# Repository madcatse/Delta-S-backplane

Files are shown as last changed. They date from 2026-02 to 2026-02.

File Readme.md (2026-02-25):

# Delta-S Backplane / Бекплейн для «Дельта‑С»

## RU

### Что это

Этот проект — печатная плата бекплейна для компьютера «Дельта‑С» (совместимая ZX‑архитектура), которая расширяет системную шину и упрощает подключение периферии.

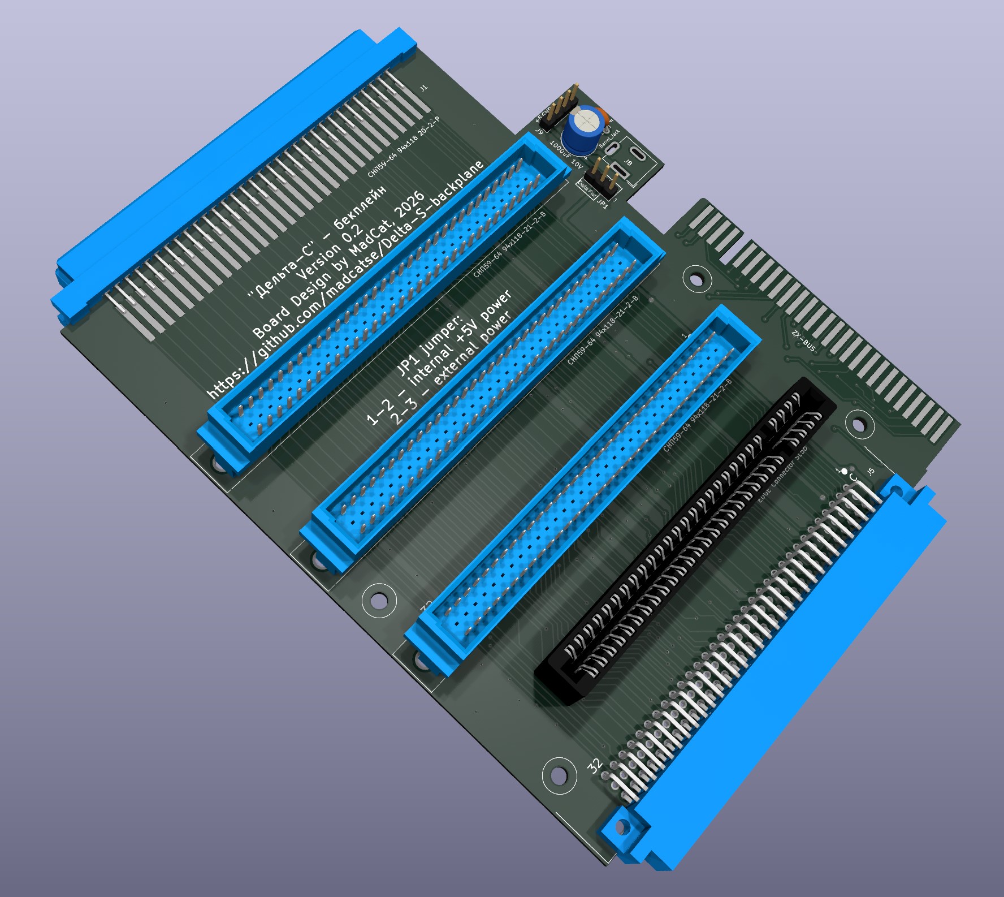
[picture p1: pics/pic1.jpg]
Вид спереди

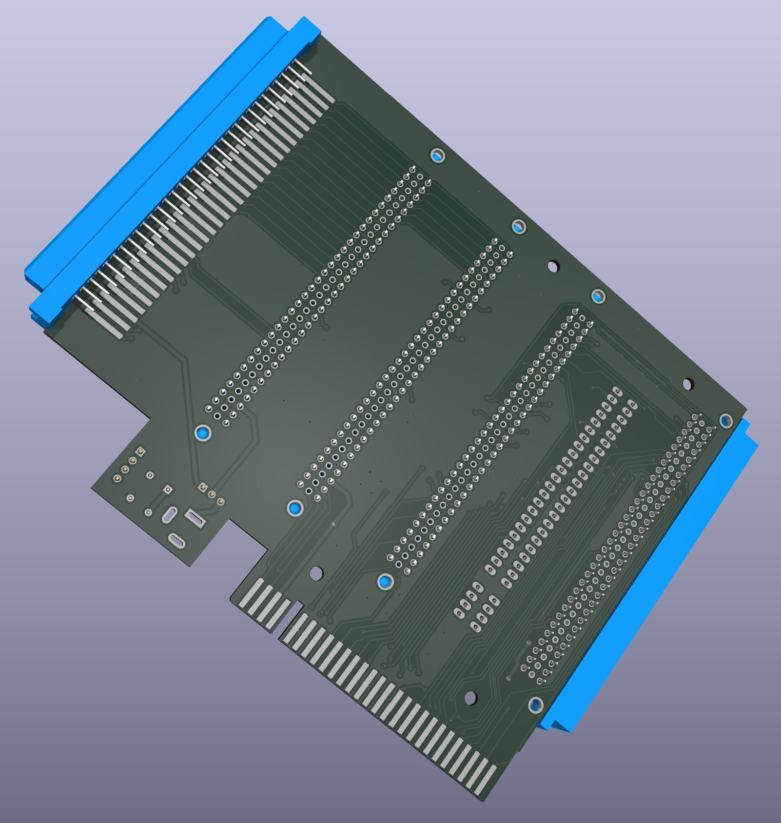
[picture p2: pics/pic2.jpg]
Вид сзади


Плата предназначена для:
- подключения нескольких дополнительных устройств через разъёмы СНП;
- вывода системных сигналов в формате ZX BUS / Nemo Bus;
- питания подключённых устройств либо от компьютера, либо от внешнего источника +5 В с аппаратным выбором источника.

---

### Ключевые возможности

- **4 слота СНП для модулей расширения** (разъёмы J2–J5).
- **Системный вход от компьютера «Дельта‑С»** через угловой СНП‑разъём (J1).
- **Выводы на внешние шины**:
  - J6 — разъём ZX‑BUS;
  - J7 — edge‑разъём формата ZX Spectrum bus.
- **Два варианта питания +5 В**:
  - внутреннее (от хоста «Дельта‑С»);
  - внешнее через barrel‑jack (J8) / штыревой разъём питания (J9).
- **Переключение источника питания джампером JP1**:
  - `1–2` — internal +5V power;
  - `2–3` — external power.
- **Фильтрация питания на плате**: C1 (1000 µF) + C2 (0.1 µF).

---

### Разъёмы и элементы

| Обозначение | Назначение |
|---|---|
| J2, J3, J4, J5 | Слоты СНП для плат расширения |
| J1 | Входной разъём к компьютеру «Дельта‑С» (магистраль бекплейна) |
| J6 | Вывод шины ZX‑BUS |
| J7 | Edge‑разъём шины (ZX Spectrum bus format) |
| J8 | Внешнее питание через DC barrel jack |
| J9 | Штыревой разъём питания/сервисный вывод (+5V/GND) |
| JP1 | Выбор источника +5 В (внутренний/внешний) |
| C1, C2 | Сглаживание и развязка питания |

> Важно: перед установкой `JP1 = 2–3` убедитесь, что внешний источник стабилизирован и соответствует **+5 В DC**.

---

### Что внутри проекта

- `deltas_backplane.kicad_sch` — электрическая схема.
- `deltas_backplane.kicad_pcb` — топология печатной платы.
- `gerbers/` — набор Gerber/Excellon для производства.
- `Libs/` — локальные библиотеки символов, футпринтов и 3D‑моделей.

Проект выполнен в формате KiCad 9‑совместимых файлов.

---

### Производство и сборка

1. Откройте `deltas_backplane.kicad_pcb` в KiCad и визуально проверьте ревизию/маркировки.
2. Используйте готовые файлы из `gerbers/` или сгенерируйте свой комплект под нужную ревизию.
3. После пайки **сначала** установите джампер питания JP1 в нужный режим, **затем** подключайте периферию.
4. При использовании внешнего источника избегайте одновременной «жёсткой» подпитки +5 В от нескольких источников.

---

### Совместимость и контекст

По структуре сигналов проект рассчитан на ZX‑совместимую экосистему «Дельта‑С» с выводом шины в форматах ZX BUS / Nemo Bus. Фактическая совместимость конкретных периферийных устройств зависит от их электрических требований, распиновки и поведения управляющих сигналов.

---

## EN

### What this project is

This repository contains a backplane PCB for the **Delta‑S** computer (ZX‑compatible ecosystem). The board extends the system bus and makes peripheral expansion easier.

It is designed to:
- connect multiple expansion devices through SNP connectors;
- expose system signals in **ZX BUS / Nemo Bus** form factors;
- power attached devices either from the host computer or from an external +5 V source (hardware selectable).

---

### Key features

- **4 SNP expansion slots** (J2–J5).
- **Host connection to Delta‑S** via angled SNP connector (J1).
- **External bus outputs**:
  - J6 — ZX‑BUS connector;
  - J7 — edge connector in ZX Spectrum bus format.
- **Dual +5 V power options**:
  - internal (from the Delta‑S host);
  - external via barrel jack (J8) / header connector (J9).
- **JP1 power source selection**:
  - `1–2` — internal +5V power;
  - `2–3` — external power.
- **Onboard power filtering**: C1 (1000 µF) + C2 (0.1 µF).

---

### Connectors and parts

| Designator | Function |
|---|---|
| J2, J3, J4, J5 | SNP slots for expansion cards |
| J1 | Upstream connector to Delta‑S host bus |
| J6 | ZX‑BUS output |
| J7 | Edge bus connector (ZX Spectrum format) |
| J8 | External power input (DC barrel jack) |
| J9 | Pin header for power/service (+5V/GND) |
| JP1 | +5 V source select (internal/external) |
| C1, C2 | Bulk/decoupling capacitors |

> Important: before setting `JP1 = 2–3`, verify that your external PSU is properly regulated at **+5 V DC**.

---

### Repository contents

- `deltas_backplane.kicad_sch` — schematic.
- `deltas_backplane.kicad_pcb` — board layout.
- `gerbers/` — manufacturing Gerber/Excellon files.
- `Libs/` — local symbols, footprints, and 3D models.

The project uses KiCad file formats compatible with KiCad 9 workflows.

---

### Manufacturing and bring‑up notes

1. Open `deltas_backplane.kicad_pcb` in KiCad and confirm board revision/silkscreen.
2. Use the prepared set in `gerbers/` (or regenerate for your target revision).
3. After assembly, set JP1 to the required power mode **before** attaching expansion cards.
4. When using external power, avoid hard‑tying multiple +5 V sources without proper isolation.

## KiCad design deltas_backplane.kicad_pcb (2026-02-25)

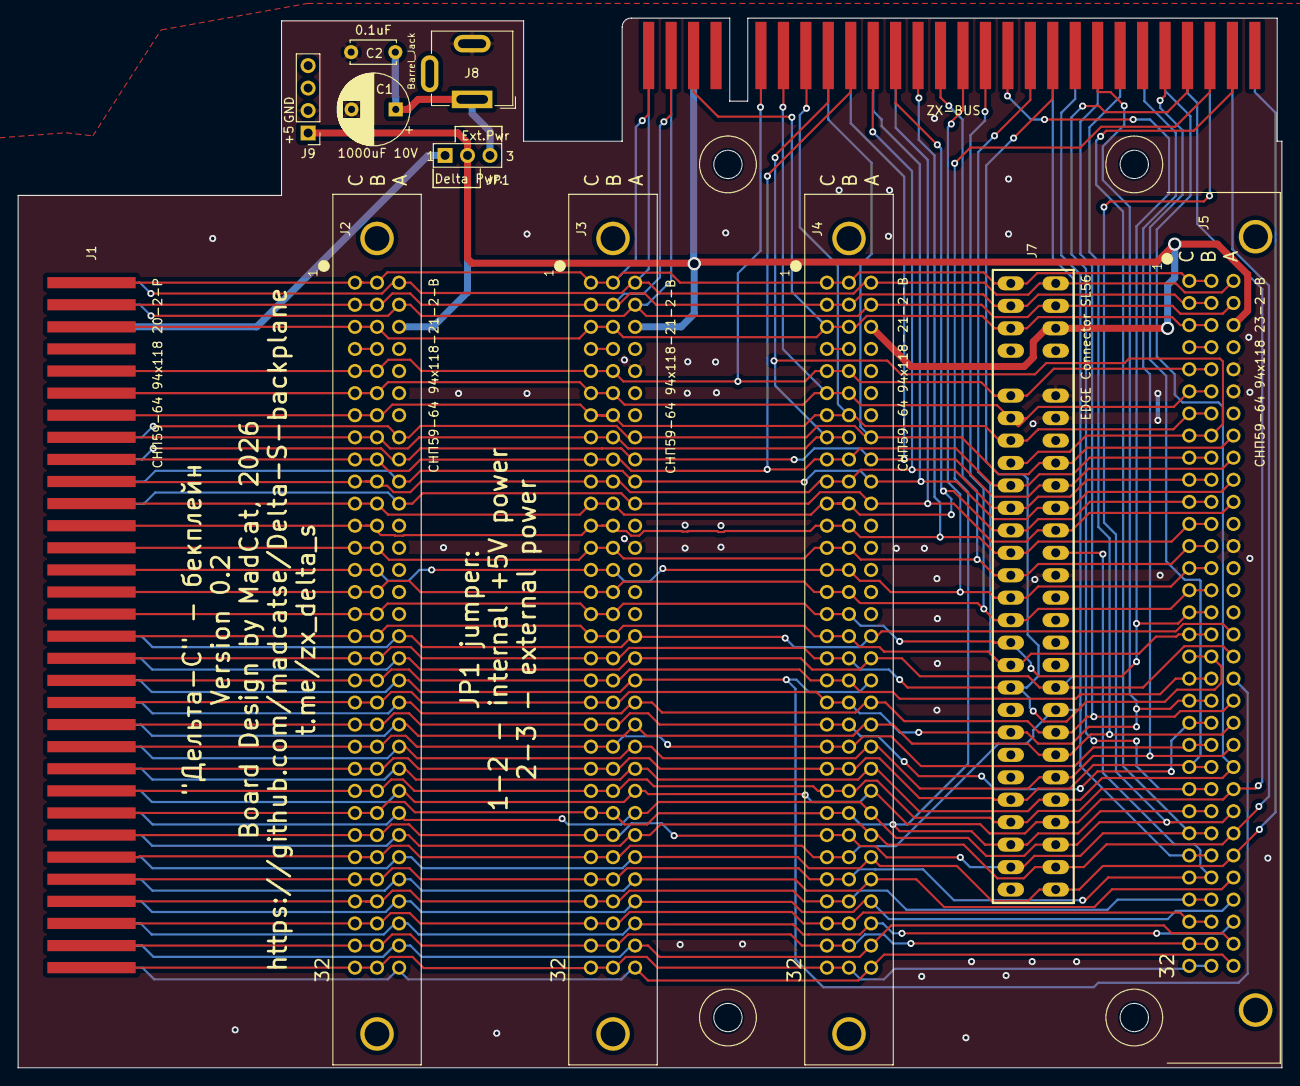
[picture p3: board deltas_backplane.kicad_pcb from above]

Board: 2 copper layers, 143.0 x 118.8 mm, 16 parts (0 on the bottom side), 57 nets.

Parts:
C1: 1000uF 10V; CP_Radial_D8.0mm_P5.00mm
C2: 0.1uF; C_Disc_D5.0mm_W2.5mm_P5.00mm
J1: СНП59-64 94х118 20-2-Р; snp_straight
J2, J3, J4: СНП59-64 94х118-21-2-В; snp59_96_male_straight
J5: СНП59-64 94х118 23-2-В; snp59_96_female_angle_3
J6: ZX-BUS; ZX SPECTRUM EDGE CONNECTOR (HORIZONTAL)
J7: EDGE Connector SL56; Spectrum_edge_slot_FIXED
J8: Barrel_Jack; BarrelJack_GCT_DCJ200-10-A_Horizontal
J9: Conn_01x04; PinHeader_1x04_P2.54mm_Vertical
JP1: Jumper_3_Open; PinHeader_1x03_P2.54mm_Vertical
M31, M31#2, M31#3, M31#4: MountingHole_3.2mm_M3

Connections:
5V_connector: J2.35 ("+5"), J3.35 ("+5"), J4.35 ("+5"), J5.35 ("+5"), J6.31 (+5V), J7.31 (+5V), J9.1, JP1.2 (C)
+5V: J1.35 ("+5"), JP1.1 (A)
A0: J1.40 (A0), J2.40 (A0), J3.40 (A0), J4.40 (A0), J5.40 (A0), J6.37 (A0), J7.37 (A0)
A1: J1.41 (A1), J2.41 (A1), J3.41 (A1), J4.41 (A1), J5.41 (A1), J6.38 (A1), J7.38 (A1)
A2: J1.42 (A2), J2.42 (A2), J3.42 (A2), J4.42 (A2), J5.42 (A2), J6.39 (A2), J7.39 (A2)
A3: J1.43 (A3), J2.43 (A3), J3.43 (A3), J4.43 (A3), J5.43 (A3), J6.40 (A3), J7.40 (A3)
A4: J1.55 (A4), J2.55 (A4), J3.55 (A4), J4.55 (A4), J5.55 (A4), J6.52 (A4), J7.52 (A4)
A5: J1.54 (A5), J2.54 (A5), J3.54 (A5), J4.54 (A5), J5.54 (A5), J6.51 (A5), J7.51 (A5)
A6: J1.53 (A6), J2.53 (A6), J3.53 (A6), J4.53 (A6), J5.53 (A6), J6.50 (A6), J7.50 (A6)
A7: J1.52 (A7), J2.52 (A7), J3.52 (A7), J4.52 (A7), J5.52 (A7), J6.49 (A7), J7.49 (A7)
A8: J1.25 (A8), J2.25 (A8), J3.25 (A8), J4.25 (A8), J5.25 (A8), J6.26 (A8), J7.26 (A8)
A9: J1.58 (A9), J2.58 (A9), J3.58 (A9), J4.58 (A9), J5.58 (A9), J6.55 (A9), J7.55 (A9)
A10: J1.26 (A10), J2.26 (A10), J3.26 (A10), J4.26 (A10), J5.26 (A10), J6.27 (A10), J7.27 (A10)
A11: J1.59 (A11), J2.59 (A11), J3.59 (A11), J4.59 (A11), J5.59 (A11), J6.56 (A11), J7.56 (A11)
A12: J1.34 (A12), J2.34 (A12), J3.34 (A12), J4.34 (A12), J5.34 (A12), J6.30 (A12), J7.30 (A12)
A13: J1.2 (A13), J2.2 (A13), J3.2 (A13), J4.2 (A13), J5.2 (A13), J6.2 (A13), J7.2 (A13)
A14: J1.33 (A14), J2.33 (A14), J3.33 (A14), J4.33 (A14), J5.33 (A14), J6.29 (A14), J7.29 (A14)
A15: J1.1 (A15), J2.1 (A15), J3.1 (A15), J4.1 (A15), J5.1 (A15), J6.1 (A15), J7.1 (A15)
A19_SNP: J1.51 (BD1), J2.51 (BD1), J3.51 (BD1), J4.51 (BD1), J5.51 (BD1)
A28_SNP: J1.60 (P5), J2.60 (P5), J3.60 (P5), J4.60 (P5), J5.60 (P5)
A29_SNP: J1.61 (BD3), J2.61 (BD3), J3.61 (BD3), J4.61 (BD3), J5.61 (BD3)
A30_SNP: J1.62 (BD5), J2.62 (BD5), J3.62 (BD5), J4.62 (BD5), J5.62 (BD5)
A31_SNP: J1.63 (BD6), J2.63 (BD6), J3.63 (BD6), J4.63 (BD6), J5.63 (BD6)
B19_SNP: J1.19 (BD2), J2.19 (BD2), J3.19 (BD2), J4.19 (BD2), J5.19 (BD2)
B21_SNP: J1.21 (P1), J2.21 (P1), J3.21 (P1), J4.21 (P1), J5.21 (P1)
B22_SNP: J1.22 (P2), J2.22 (P2), J3.22 (P2), J4.22 (P2), J5.22 (P2)
B28_SNP: J1.28 (P4), J2.28 (P4), J3.28 (P4), J4.28 (P4), J5.28 (P4), J7.41 (NC)
B29_SNP: J1.29 (P5), J2.29 (P5), J3.29 (P5), J4.29 (P5), J5.29 (P5)
B30_SNP: J1.30 (BD4), J2.30 (BD4), J3.30 (BD4), J4.30 (BD4), J5.30 (BD4)
B31_SNP: J1.31 (BD0), J2.31 (BD0), J3.31 (BD0), J4.31 (BD0), J5.31 (BD0)
B32_SNP: J1.32 (BD7), J2.32 (BD7), J3.32 (BD7), J4.32 (BD7), J5.32 (BD7)
BUSY: J1.64 (ГТ), J2.64 (ГТ), J3.64 (ГТ), J4.64 (ГТ), J5.64 (ГТ)
D0: J1.5 (D0), J2.5 (D0), J3.5 (D0), J4.5 (D0), J5.5 (D0), J6.6 (D0), J7.6 (D0)
D1: J1.6 (D1), J2.6 (D1), J3.6 (D1), J4.6 (D1), J5.6 (D1), J6.7 (D1), J7.7 (D1)
D2: J1.7 (D2), J2.7 (D2), J3.7 (D2), J4.7 (D2), J5.7 (D2), J6.8 (D2), J7.8 (D2)
D3: J1.10 (D3), J2.10 (D3), J3.10 (D3), J4.10 (D3), J5.10 (D3), J6.11 (D3), J7.11 (D3)
D4: J1.11 (D4), J2.11 (D4), J3.11 (D4), J4.11 (D4), J5.11 (D4), J6.12 (D4), J7.12 (D4)
D5: J1.9 (D5), J2.9 (D5), J3.9 (D5), J4.9 (D5), J5.9 (D5), J6.10 (D5), J7.10 (D5)
D6: J1.8 (D6), J2.8 (D6), J3.8 (D6), J4.8 (D6), J5.8 (D6), J6.9 (D6), J7.9 (D6)
D7: J1.3 (D7), J2.3 (D7), J3.3 (D7), J4.3 (D7), J5.3 (D7), J6.3 (D7), J7.3 (D7)
GND: C1.2, C2.2, J1.37 (Общий), J1.38 (Общий), J1.45 (Общий), J2.37 (Общий), J2.38 (Общий), J2.45 (Общий), J3.37 (Общий), J3.38 (Общий), J3.45 (Общий), J4.37 (Общий), J4.38 (Общий), J4.45 (Общий), J5.37 (Общий), J5.38 (Общий), J5.45 (Общий), J6.34 (GND), J6.35 (GND), J6.42 (GND), J7.34 (GND), J7.35 (GND), J7.42 (GND), J8.2, J9.2
M1L: J1.23 (М1), J2.23 (М1), J3.23 (М1), J4.23 (М1), J5.23 (М1), J6.24 (M1), J7.24 (M1)
unnamed: C1.1, C2.1, J8.1, JP1.3 (B)
STROBL: J1.49 (СТР), J2.49 (СТР), J3.49 (СТР), J4.49 (СТР), J5.49 (СТР)
ВУL: J1.16 (ВУ), J2.16 (ВУ), J3.16 (ВУ), J4.16 (ВУ), J5.16 (ВУ), J6.17 (IORQ), J7.17 (IORQ)
ЗАПРШL: J1.50 (ЗАПРШ), J2.50 (ЗАПРШ), J3.50 (ЗАПРШ), J4.50 (ЗАПРШ), J5.50 (ЗАПРШ), J6.47 (BUSRQ), J7.47 (BUSRQ)
ЗПL: J1.18 (ЗП), J2.18 (ЗП), J3.18 (ЗП), J4.18 (ЗП), J5.18 (ЗП), J6.19 (WR), J7.19 (WR)
НПРL: J1.13 (НПР), J2.13 (НПР), J3.13 (НПР), J4.13 (НПР), J5.13 (НПР), J6.14 (NMI), J7.14 (NMI)
ОЖИДL: J1.20 (ОЖИД), J2.20 (ОЖИД), J3.20 (ОЖИД), J4.20 (ОЖИД), J5.20 (ОЖИД), J6.21 (WAIT), J7.21 (WAIT)
ОЗУL: J1.15 (ОЗУ), J2.15 (ОЗУ), J3.15 (ОЗУ), J4.15 (ОЗУ), J5.15 (ОЗУ), J6.16 (MREQ), J7.16 (MREQ)
ПЗШL: J1.57 (ПЗШ), J2.57 (ПЗШ), J3.57 (ПЗШ), J4.57 (ПЗШ), J5.57 (ПЗШ), J6.54 (BUSACK), J7.54 (BUSACK)
ПРL: J1.12 (ПР), J2.12 (ПР), J3.12 (ПР), J4.12 (ПР), J5.12 (ПР), J6.13 (INT), J7.13 (INT)
РГНL: J1.24 (РГН), J2.24 (РГН), J3.24 (РГН), J4.24 (РГН), J5.24 (РГН), J6.25 (RFSH), J7.25 (RFSH)
СБРОСL: J1.27 (СБРОС), J2.27 (СБРОС), J3.27 (СБРОС), J4.27 (СБРОС), J5.27 (СБРОС), J6.48 (RESET), J7.48 (RESET)
СТОПL: J1.14 (СТОП), J2.14 (СТОП), J3.14 (СТОП), J4.14 (СТОП), J5.14 (СТОП), J6.15 (HALT), J7.15 (HALT)
ЧТL: J1.17 (ЧТ), J2.17 (ЧТ), J3.17 (ЧТ), J4.17 (ЧТ), J5.17 (ЧТ), J6.18 (RD), J7.18 (RD)
ЧТПЗУL: J1.56 (БЛК_ПЗУ), J2.56 (БЛК_ПЗУ), J3.56 (БЛК_ПЗУ), J4.56 (БЛК_ПЗУ), J5.56 (БЛК_ПЗУ), J6.53 (ROMCS), J7.53 (ROMCS)

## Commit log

2023-10-02 Initial upload
    [deltas_backplane.kicad_pcb, deltas_backplane.kicad_sch]
2023-10-03 Power fix
    [deltas_backplane.kicad_sch]
2023-10-03 03.10.2023 update
    [deltas_backplane.kicad_pcb, deltas_backplane.kicad_sch]
2023-10-10 Gerbers upload
    [deltas_backplane.kicad_pcb]
2023-10-10 Small update (0.1.1)
    [deltas_backplane.kicad_pcb]
2026-02-25 Version 0.2 upload
    [deltas_backplane-B_Cu.gbr, deltas_backplane-B_Mask.gbr, deltas_backplane-B_Silkscreen.gbr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]
